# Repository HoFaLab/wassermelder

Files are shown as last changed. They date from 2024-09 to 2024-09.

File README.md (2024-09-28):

# HoFaLab Wassermelder
A simple water alarm using a float switch and a Raspberry Pi Pico W with practically infinite standby battery life.

TODO: add part number of used float switch.
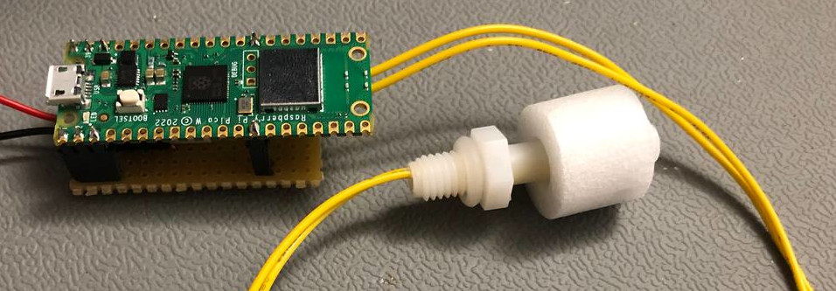
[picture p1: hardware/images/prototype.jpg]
Picture of the built project on a perfboard


## About this repository

This repository has two main parts.

| path | description |
|---|---|
| [hardware](hardware/README.md) | A KiCAD project describing the hardware |
| [firmware](firmware/README.md) | Micropython files as the firmware |

The firmware uses submodules, so you need to clone recursively
``` bash
git clone --recursive https://github.com/HoFaLab/wassermelder.git
```

## Project description
The goal of this project was a water alarm at a sump in a basement. The main focus was on simplicity and long battery life.

The microcontroller is completely disconnected form the battery until the float switch is triggered by the water. This ensures basically unlimited battery life.

## Acknowledgements
This project was completed using some great resources:

| resource | source |
|---|---|
| KiCAD symbol and component for *Raspberry Pi Pico W*  | https://github.com/bdubs-astro/Raspberry_Pi_Pico_W_Kicad_Files |
| .gitignore file for KiCAD | https://github.com/github/gitignore/blob/main/KiCad.gitignore  |
| utelegram library for micropython | https://github.com/jordiprats/micropython-utelegram |

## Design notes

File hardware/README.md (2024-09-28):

# Wassermelder Hardware

To achieve a practically unlimited battery life, a small circuit is needed.

## description of operation

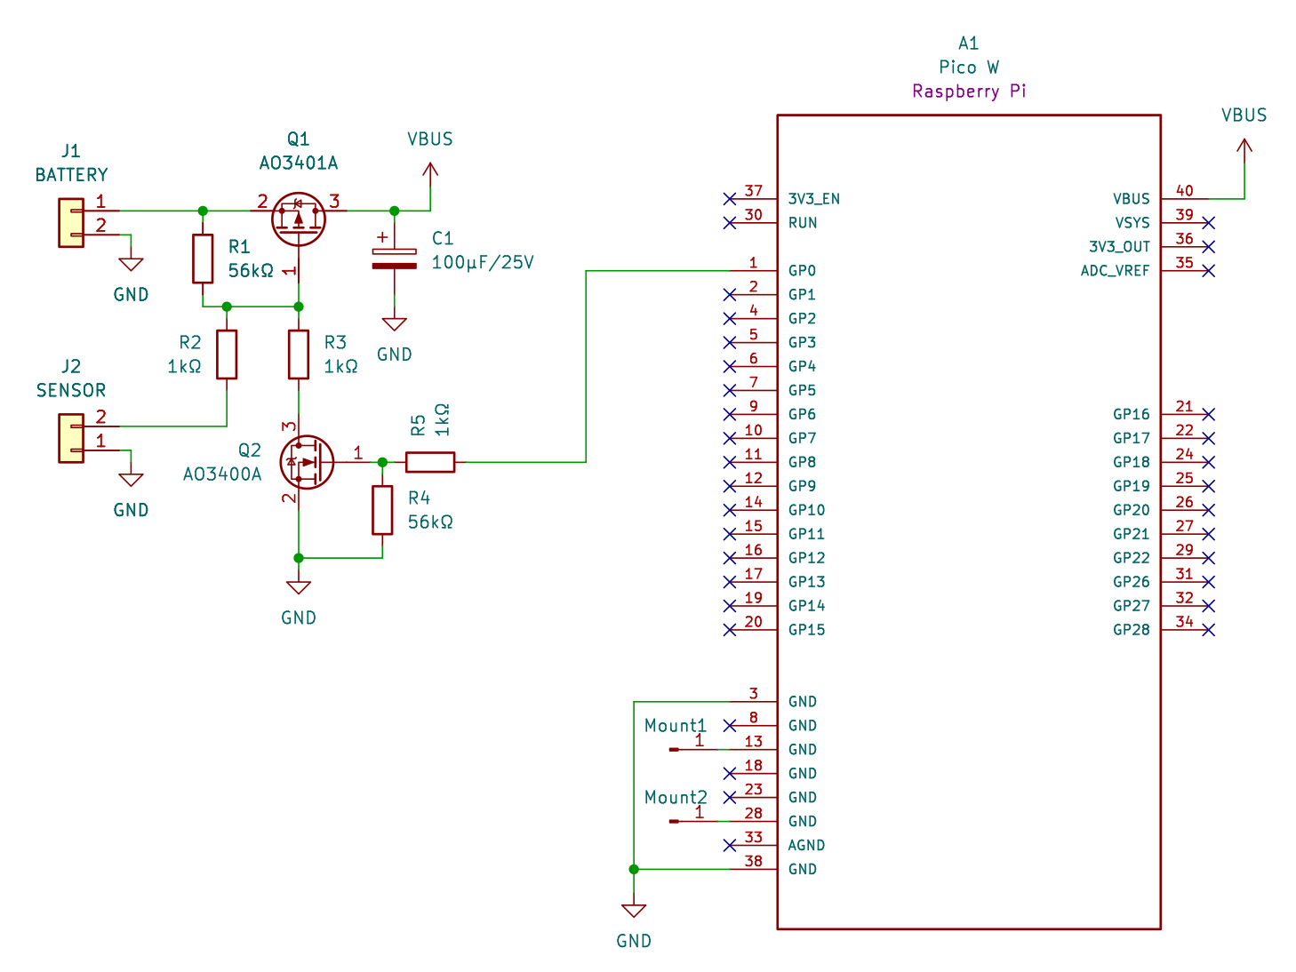
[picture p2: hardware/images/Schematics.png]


The voltage from the battery (J1) is disconnected from the Pico W via the P-FET transistor Q1. The resistor R1 pulls the gate of Q1 high and the transistor shut off.
When the water sensor triggers, it pulls the gate of Q1 via R2 low, because the Resistance of R2 is a lot lower than R1. This pulls the gate voltage of Q1 below it's threshold voltage, allowing it to conduct and powering on the Pico W. The capacitor C1 stabilizes the voltage for the Pico W.
The very first action of the Pico W is to pull it's pin GP0 high. This makes The N-FET conductive, further pulling the base of Q1 low, keeping it conductive. Even if the water sensor now resets, the Pico W keeps it's own power supply active.
After the Pico W finishes it's job to to alert via Telegram, it pulls it's pin GP0 low again. Once the water sensor resets, this allows Q1 to stop conducting current, and shutting off all power again.

## Bill of Materials

| Reference  | Part Number | Description |
|---|---|---|
| A1 | SC0918 | Raspberry Pi Pico W |
| | TODO | water float switch |
| R1, R4 | 56kΩ 0805 | 56kΩ resistor |
| R2, R3, R5 | 10kΩ 0805 | 10kΩ resistor |
| Q1 | AO3401A | P-FET transistor |
| Q2 | AO3400A | N-FET transistor |
| J1, J2 | JST PH2P ST90 | battery and water sensor connectors |

Additionally you need:
- pinheaders and pinsockets with 2,54mm pitch
- a perfboard, suitably sized
- a suitable battery (preferrably a LiIon or LiPo for their voltage)
- a case, e.g. 3D printed

## Hardware construction
I've constructed the circuit on a small perfboard with a combination of SMD and THT parts. Even if the usage of SMD parts on a perfboard is not conventional, it offers a very small layout, and is still hand-solderable with a bit of practice.

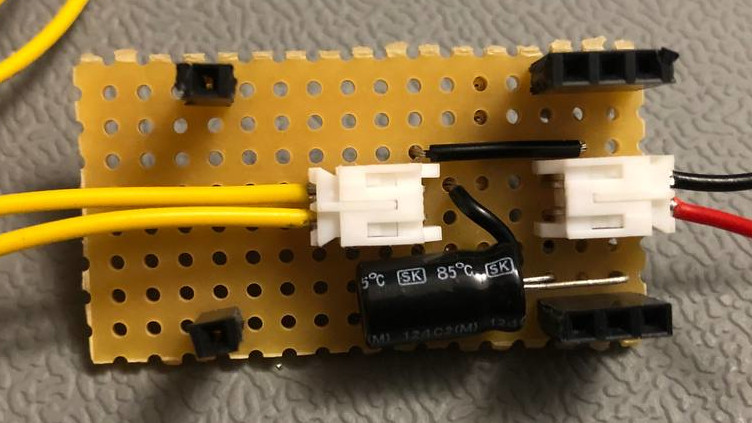
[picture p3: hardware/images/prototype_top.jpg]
top side of completed perfboard without Pico W

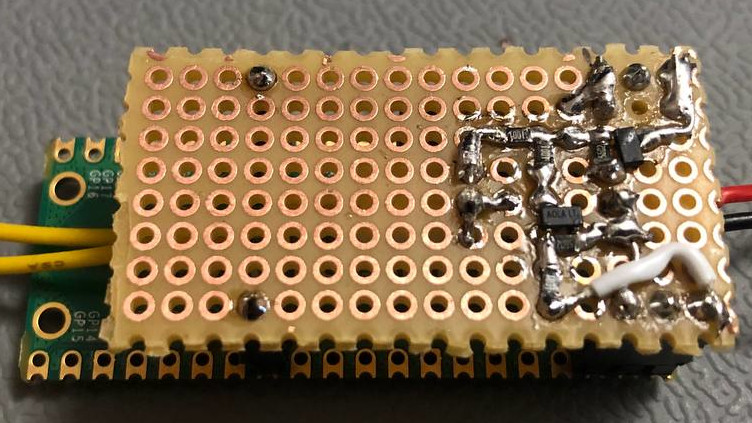
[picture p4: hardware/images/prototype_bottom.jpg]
bottom side of completed perfboard


## KiCad files
The KiCAD layout isn't a production-ready PCB design. But it shows the rough position and interconnection of the components I chose on the perfboard.

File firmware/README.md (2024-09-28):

# Wassermelder firmware

This water alarm is running on a *Raspberry Pi Pico W* using [MicroPython](https://micropython.org/download/RPI_PICO_W/).

## Preparation
Before loading the firmware to the Pico W, there are a few steps to do.

### 1. Flash MicroPython to the Pico W
Flash the latest MicroPyhton firmware to the Pico W. This step has do be done only once.
1. Go to [https://micropython.org/download/RPI_PICO_W/](https://micropython.org/download/RPI_PICO_W/) and download the latest MicroPython .u2f binary.
2. Keep the button "BOOTSEL" pressed while connecting the Pico W to the computer. It will show up as a USB mass storage device.
3. Then simply copy the .u2f file to the Pico W. The Pico W will dismount once the proccess is complete.

### 2. Add WiFi and Telegram credentials
Rename the file `my_config.py.example` to `my_config.py` and add your WiFi credentials as well as your Telegram token, chat id and alarm message.

### 3. Install ampy (optional)
I use Adafruit's tool **ampy** (adafruit-ampy) to copy the python files to the Pico W. You can install it with:
``` bash
pip install -r requirements.txt
```

## Uploading the firmware

You can use the `upload.sh` bash script to upload the program files to the Pico W. 
You may need to modify the `AMPY_PORT` for your system.

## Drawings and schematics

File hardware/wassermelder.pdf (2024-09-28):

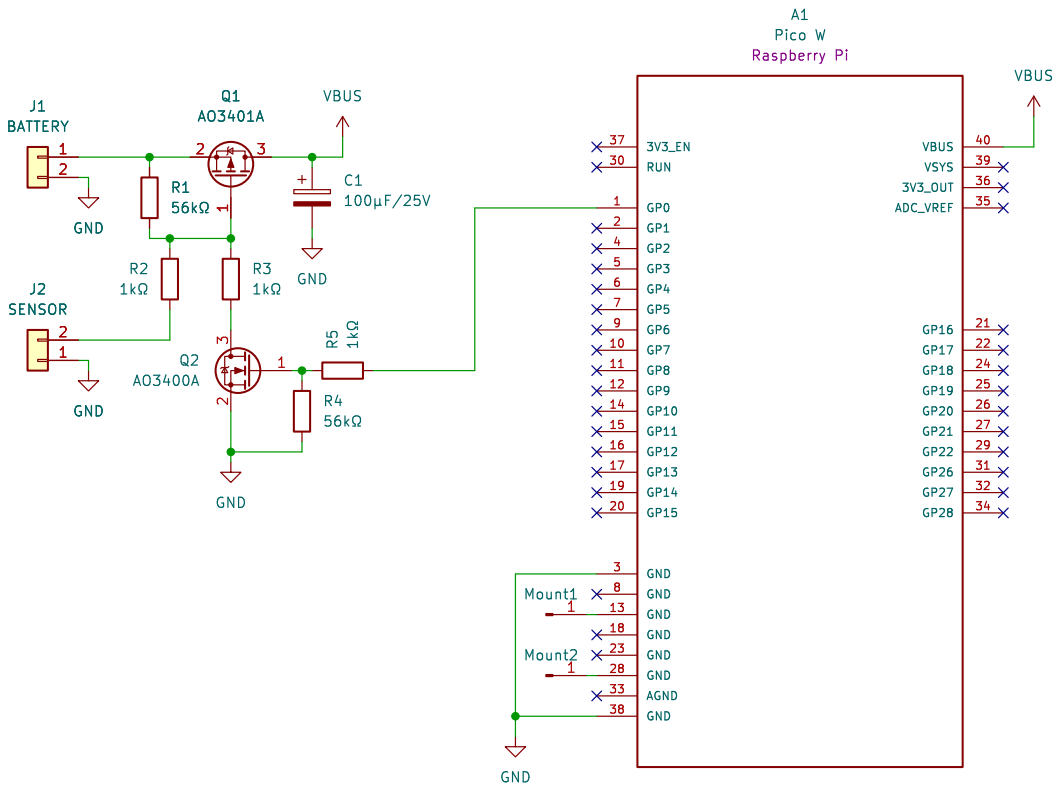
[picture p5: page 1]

Id: 1/1 Title: Wassermelder File: wassermelder.kicad_sch Sheet: / GND

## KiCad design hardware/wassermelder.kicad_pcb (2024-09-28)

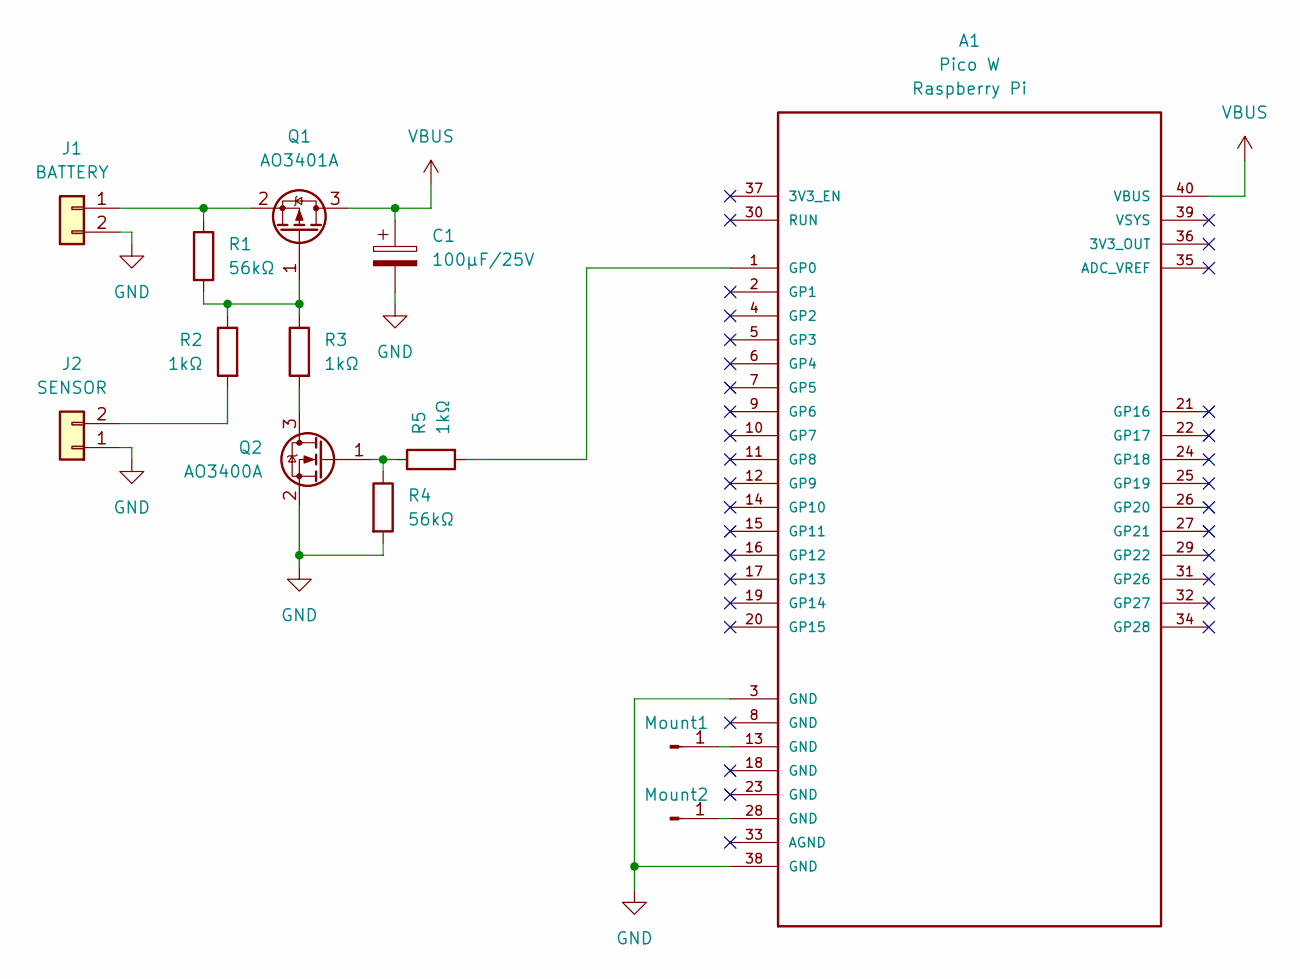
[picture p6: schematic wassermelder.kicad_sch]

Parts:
A1: Pico W; MODULE_SC0918; PARTREV 1.6
C1: 100µF/25V; CP_Radial_D6.3mm_P2.50mm
J1: BATTERY; JST_PH_S2B-PH-K_1x02_P2.00mm_Horizontal
J2: SENSOR; JST_PH_S2B-PH-K_1x02_P2.00mm_Horizontal
Mount1, Mount2: Conn_01x01_Male; PinHeader_1x01_P2.54mm_Vertical
Q1: AO3401A; SOT-23
Q2: AO3400A; SOT-23
R1, R4: 56kΩ; R_0805_2012Metric
R2, R3, R5: 1kΩ; R_0805_2012Metric

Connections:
GND: A1.3 (GND), A1.38 (GND), C1.2, J1.2, J2.1, Q2.2 (S), R4.2
unnamed: A1.1 (GP0), R5.2
unnamed: J1.1, Q1.2 (S), R1.1
unnamed: J2.2, R2.2
unnamed: A1.13 (GND), Mount1.1
unnamed: A1.28 (GND), Mount2.1
unnamed: Q1.1 (G), R1.2, R2.1, R3.1
unnamed: Q2.1 (G), R4.1, R5.1
unnamed: Q2.3 (D), R3.2
VBUS: A1.40 (VBUS), C1.1, Q1.3 (D)

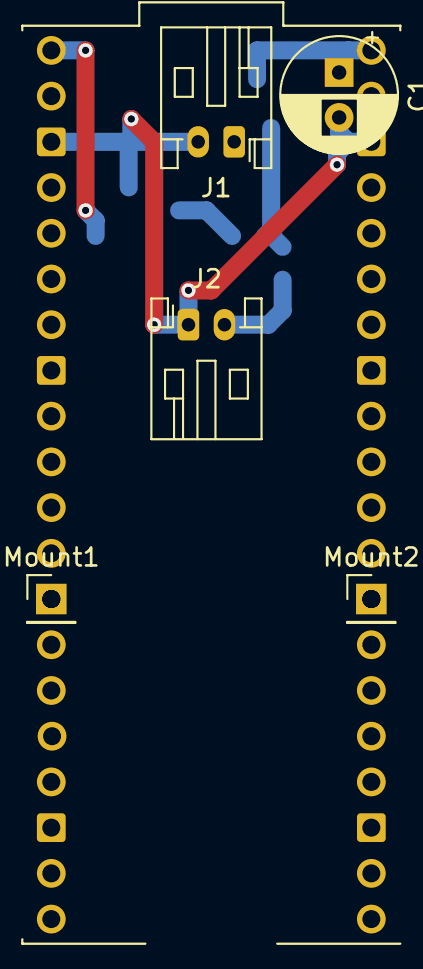
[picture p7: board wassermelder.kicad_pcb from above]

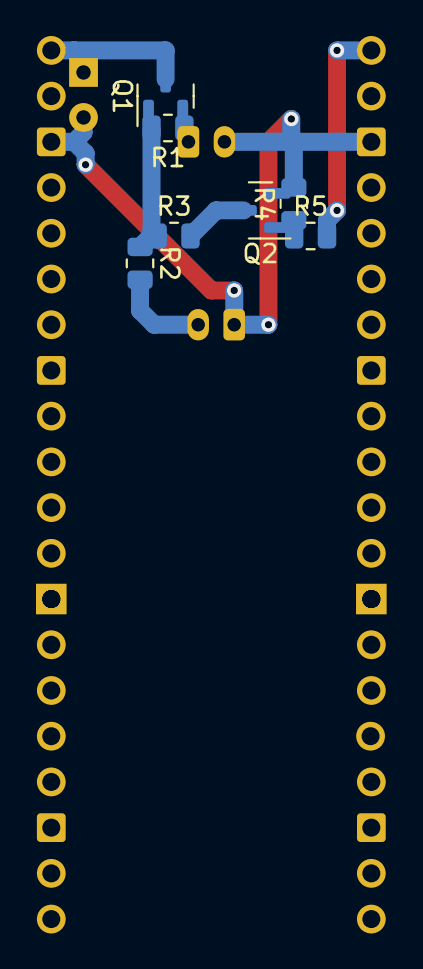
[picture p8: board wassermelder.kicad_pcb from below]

Board: 2 copper layers, 13 parts (7 on the bottom side), 10 nets.

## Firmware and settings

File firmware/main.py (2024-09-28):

from machine import Pin
keepalive = Pin(0, Pin.OUT)
keepalive.on() # set keepalive pin as soon as possible


from time import sleep
import network
import utelegram.utelegram as utelegram
import my_config


led = Pin("LED", Pin.OUT)
led.on()


def connect():
    #Connect to WLAN
    wlan = network.WLAN(network.STA_IF)
    print(f"MAC: {wlan.config('mac').hex()}")
    wlan.active(True)
    if not wlan.isconnected():
        try:
            wlan.connect(my_config.wifi_config['ssid'], my_config.wifi_config['pass'])
        except OSError:
            return False
    while wlan.isconnected() == False:
        print('Waiting for connection...')
        sleep(1)
    ip = wlan.ifconfig()[0]
    print(f'Connected on {ip}')
    return True


def send_message():
    bot = utelegram.ubot(my_config.telegram_config['token'])
    if bot.send(my_config.telegram_config['chat_id'], my_config.telegram_config['text']):
        return True
    else:
        for _ in range(20):
            led.toggle()
            sleep(0.2)
        return False
        

def main():
    while True:
        sleep(1)
        try:
            if not connect():
                continue
            if send_message():
                return 0
        except KeyboardInterrupt:
            return 0
        except:
            continue
    

if __name__ == "__main__":
    main()
    led.off()
    keepalive.off()
